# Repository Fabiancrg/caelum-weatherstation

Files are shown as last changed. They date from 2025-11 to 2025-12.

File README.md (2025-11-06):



| Supported Targets | ESP32-C6 | ESP32-H2 |
| --- |  --- | --- |

# Caelum - Zigbee Weather Station




## Project Description

This project implements a battery-powered environmental monitoring device using ESP32-C6/H2 with Zigbee connectivity. The device features a 3-endpoint design with remote sleep configuration, optimized for low-power operation with deep sleep support and extended wake time during network join.

This project is based on the examples provided in the ESP Zigbee SDK:

* [ESP Zigbee SDK Docs](https://docs.espressif.com/projects/esp-zigbee-sdk)
* [ESP Zigbee SDK Repo](https://github.com/espressif/esp-zigbee-sdk)

## Device Features

### 🌐 Zigbee Endpoints Overview

| Endpoint | Device Type | Clusters | Description |
|---|---|---|---|
| **1** | Environmental Sensor | Temperature, Humidity, Pressure, Battery, OTA | BME280 sensor via I2C |
| **2** | Rain Gauge | Analog Input | Tipping bucket rain sensor with rainfall totals |
| **3** | Sleep Configuration | Analog Input | Remote sleep duration control (60-7200 seconds) |
| **4** | LED Debug Control | On/Off | WS2812 RGB LED status indicator (remote control) |

### 💡 LED Debug Feature (Optional)

The device includes an optional WS2812 RGB LED on GPIO8 (ESP32-H2 SuperMini) that provides visual feedback:
- **Blue (Steady)**: Connected to Zigbee network
- **Orange (Blinking)**: Joining/searching for network  
- **White (Brief Flash)**: Rain pulse detected
- **Off**: Deep sleep or disabled via Zigbee

This feature can be controlled remotely via Zigbee2MQTT (endpoint 4) and disabled to conserve battery. See [LED_DEBUG_FEATURE.md](LED_DEBUG_FEATURE.md) for complete documentation.

### 📋 Detailed Endpoint Descriptions

#### **Endpoint 1: Environmental Monitoring & Power Management**
- **Hardware**: BME280 sensor via I2C
  - **ESP32-H2**: SDA: GPIO10, SCL: GPIO11
  - **ESP32-C6**: SDA: GPIO6, SCL: GPIO7
- **Measurements**: 
  - 🌡️ **Temperature**: -40°C to +85°C (±1°C accuracy)
  - 💧 **Humidity**: 0-100% RH (±3% accuracy) 
  - 🌪️ **Pressure**: 300-1100 hPa (±1 hPa accuracy)
  - 🔋 **Battery Monitoring**: Li-Ion voltage (2.7V-4.2V) and percentage
- **Battery Monitoring**:
  - **Hardware**: GPIO4 (ADC1_CH4) with voltage divider (2x 100kΩ resistors)
  - **Voltage**: Real-time battery voltage in 0.1V units
  - **Percentage**: Battery level 0-100% based on Li-Ion discharge curve
  - **Calibration**: ESP32-H2 ADC correction factor (1.604x) for accurate readings
  - **Power Configuration Cluster**: Standard Zigbee battery attributes
  - **Optimized Reading**: 
    - Time-based hourly intervals (3600 seconds) with NVS persistence
    - 3 ADC samples (reduced from 10) for ~70% ADC power savings
    - No delays between samples for ~90% overhead reduction
    - Total battery monitoring power: ~12µAh/day (98% reduction from ~480µAh/day)
    - Always reports on first boot/pairing, then hourly regardless of wake frequency
- **Features**: Automatic reporting during wake cycles, Zigbee-standard units
- **Use Case**: Weather monitoring, HVAC automation, air quality tracking, battery-powered applications

#### **Endpoint 2: Rain Gauge System**
- **Hardware**: Tipping bucket rain gauge with reed switch
  - **ESP32-H2**: GPIO12 (RTC-capable for sleep wake-up)
  - **ESP32-C6**: GPIO5 (RTC-capable for sleep wake-up)
- **Measurements**: Cumulative rainfall in millimeters (0.36mm per tip)
- **Features**: 
  - Advanced debouncing (200ms + 1000ms bounce settle)
  - Persistent storage (NVS) for total tracking
  - Smart reporting (1mm threshold OR hourly)
  - Network-aware operation (only active when connected)
  - **Both targets**: Wake from deep sleep on rain detection
  - **Time-based hourly reading**: Uses NVS persistence to ensure true 1-hour intervals regardless of wake frequency
- **Specifications**: 
  - Maximum rate: 200mm/hour supported
  - Accuracy: ±0.36mm per bucket tip
  - Storage: Non-volatile total persistence across reboots
  - Rain-proof interval tracking: Hourly battery reading even during frequent rain events
- **Use Case**: Weather station, irrigation control, flood monitoring

#### **Endpoint 3: Sleep Configuration**
- **Hardware**: Software-only (virtual endpoint)
- **Control**: Sleep duration in seconds (60-7200s range)
- **Features**:
  - Remote configuration via Zigbee2MQTT or Home Assistant
  - Persistent storage (NVS) - survives reboots
  - Real-time updates - changes apply on next wake cycle
  - Default: 900 seconds (15 minutes)
- **Use Case**: 
  - Battery optimization (longer intervals = longer battery life)
  - Seasonal adjustments (frequent updates in rainy season)
  - Dynamic power management based on weather conditions

#### **Endpoint 4: LED Debug Control**
- **Hardware**: WS2812 RGB LED (ESP32-H2 SuperMini)
  - **GPIO**: GPIO8
  - **Driver**: espressif/led_strip ~2.0.0
- **LED States**:
  - 🔵 **Blue (Steady)**: Connected to Zigbee network
  - 🟠 **Orange (Blinking)**: Searching/joining network
  - ⚪ **White (Flash)**: Rain pulse detected (100ms)
  - ⚫ **Off**: Deep sleep or disabled
- **Control**: On/Off cluster for remote enable/disable
- **Features**:
  - Remote control via Zigbee2MQTT switch
  - Default state: Enabled (ON)
  - Minimal battery impact (~20mA when active, off during sleep)
  - Visual feedback for debugging and network status
- **Use Case**: 
  - Development and testing (visual network status)
  - Field deployment debugging
  - Can be disabled remotely to conserve battery
- **Documentation**: See [LED_DEBUG_FEATURE.md](LED_DEBUG_FEATURE.md) for details

### 🔧 Hardware Configuration

#### **Required Components**
- ESP32-C6 or ESP32-H2 development board
- BME280 environmental sensor module
- Tipping bucket rain gauge with reed switch
- Li-Ion battery (with protection circuit, 5V output recommended)
- Voltage divider (2x 100kΩ resistors for battery monitoring)
- Zigbee coordinator (ESP32-H2 or commercial gateway)

#### **Pin Assignments**

**ESP32-H2 (Recommended)**
```
GPIO 4  - Battery voltage input (ADC1_CH4 with voltage divider)
GPIO 8  - WS2812 RGB LED (debug indicator, optional)
GPIO 9  - Built-in button (factory reset)
GPIO 10 - I2C SDA (BME280)
GPIO 11 - I2C SCL (BME280) 
GPIO 12 - Rain gauge input (RTC-capable)*
```

**ESP32-C6**
```
GPIO 4  - Battery voltage input (ADC1_CH4 with voltage divider)
GPIO 5  - Rain gauge input (RTC-capable)*
GPIO 6  - I2C SDA (BME280)
GPIO 7  - I2C SCL (BME280) 
GPIO 9  - Built-in button (factory reset)
```

*Both targets now use RTC-capable GPIO pins for rain detection during deep sleep

**Battery Voltage Divider Circuit**
```
Battery+ ──┬── 100kΩ ──┬── 100kΩ ── GND
           │           │
           │           └── GPIO4 (ADC input)
           │
           └── 5V output (to ESP32 power)
```
Note: Voltage divider monitors the cell voltage (2.7V-4.2V) while the battery pack provides 5V regulated output

### � Zigbee Integration
- **Protocol**: Zigbee 3.0  
- **Device Type**: End Device (sleepy end device for battery operation)
- **Supported Channels**: 11-26 (2.4 GHz)
- **Compatible**: Zigbee2MQTT, Home Assistant ZHA, Hubitat
- **OTA Support**: Over-the-air firmware updates enabled (see [OTA_GUIDE.md](OTA_GUIDE.md))

### ⚡ Power Management
- **Deep Sleep Mode**: Configurable intervals (60-7200 seconds, default 15 minutes)
  - **Configurable via Zigbee2MQTT**: Adjust sleep duration remotely from Home Assistant
  - **Connected**: Uses configured interval (default 15 minutes)
  - **Disconnected**: 30-second intervals for quick reconnection
  - **Max retries**: After 20 attempts (10 minutes), reduces to half configured duration
  - **Extended wake time**: Device stays awake for 60 seconds when not connected (instead of 10s) to allow Zigbee join process to complete
- **Wake-up Sources**:
  - Timer (configurable 60-7200 seconds)
  - **Rain detection during deep sleep** (both targets support RTC wake-up)
    - **ESP32-H2**: GPIO12 (RTC-capable)
    - **ESP32-C6**: GPIO5 (RTC-capable)
- **Network Retry Logic**: 
  - Prevents deep sleep when not connected to ensure reliable pairing
  - Extended 60-second wake period for join process completion
  - Connection success triggers 15-second reporting window before sleep
- **Battery Life**: Optimized for extended operation on battery power
  - **Total Power Consumption**: ~230µAh/day (optimized from ~700µAh/day)
  - **Battery monitoring**: ~12µAh/day (hourly readings with time-based intervals)
  - **Deep sleep**: 7-10µA baseline
  - **Active time**: ~100mA during 15-minute wake cycles
- **Battery Estimate**: 
  - **2500mAh battery**: ~10.9 years (optimized from ~3.5 years)
  - **Optimization breakdown**: 
    - 3 ADC samples instead of 10 (70% ADC power savings)
    - No delays between samples (90% overhead reduction)
    - Time-based hourly intervals (vs. every wake cycle)
    - Total battery monitoring: 98% power reduction

## 🚀 Quick Start

### Prerequisites

```bash
# Install ESP-IDF v5.5.1 or later
git clone -b v5.5.1 --recursive https://github.com/espressif/esp-idf.git
cd esp-idf
# For ESP32-H2 (recommended)
./install.sh esp32h2
# For ESP32-C6
./install.sh esp32c6
. ./export.sh
```

### Configure the Project
```bash
# For ESP32-H2 (recommended for better power management)
idf.py set-target esp32h2
# For ESP32-C6  
idf.py set-target esp32c6
idf.py menuconfig
```

### Build and Flash
```bash
# Erase previous data (recommended for first flash)
idf.py -p [PORT] erase-flash

# Build and flash the project
idf.py -p [PORT] flash monitor
```

### 🛠️ Configuration

### Device Operation

#### **Factory Reset**
- **Built-in Button (GPIO 9)**:
  - Long press (5s): Factory reset device

#### **Automatic Features**
- Environmental data reported during wake cycles
- Rain gauge totals stored persistently in NVS
- Smart rainfall reporting (1mm increments or hourly)
- Network connection status monitoring
- Deep sleep after data reporting (15-second window when connected, 60 seconds when not connected)
- Sleep duration remotely configurable via Zigbee2MQTT (60-7200 seconds)

### 📡 Data Reporting
- **Temperature/Humidity/Pressure**: Reported during wake cycles
- **Rainfall**: Immediate on tip detection (>1mm) or hourly
- **Sleep Duration**: Configurable 60-7200 seconds (default 15 minutes)
- **Sleep Cycle**: Configurable via Endpoint 3 for battery optimization

## 📊 Example Output

### Device Initialization
```
I (403) app_start: Starting scheduler on CPU0
I (408) WEATHER_STATION: Initialize Zigbee stack
I (558) WEATHER_STATION: Deferred driver initialization successful
I (568) WEATHER_STATION: BME280 sensor initialized successfully
I (578) WEATHER_STATION: Rain gauge initialized. Current total: 0.00 mm
I (578) WEATHER_STATION: Start network steering
```

### Network Connection
```
I (3558) WEATHER_STATION: Joined network successfully (Extended PAN ID: 74:4d:bd:ff:fe:63:f7:30, PAN ID: 0x13af, Channel:13, Short Address: 0x7c16)
I (3568) RAIN_GAUGE: Rain gauge enabled - device connected to Zigbee network
```

### Sensor Data Reporting
```
I (8000) WEATHER_STATION: 🌡️ Temperature: 22.35°C reported to Zigbee  
I (8010) WEATHER_STATION: 💧 Humidity: 45.20% reported to Zigbee
I (8020) WEATHER_STATION: 🌪️ Pressure: 1013.25 hPa reported to Zigbee
I (8030) BATTERY: 🔋 Li-Ion Battery: 4.17V (98%) - Zigbee values: 41 (0.1V), 196 (%*2)
I (8040) WEATHER_STATION: 📡 Temp: 22.4°C
I (8050) WEATHER_STATION: 📡 Humidity: 45.2%
I (8060) WEATHER_STATION: 📡 Pressure: 1013.3 hPa
```

### Rain Gauge Activity
```  
I (10000) RAIN_GAUGE: 🔍 Rain gauge interrupt received on GPIO18 (enabled: YES)
I (10010) RAIN_GAUGE: 🌧️ Rain pulse #1 detected! Total: 0.36 mm (+0.36 mm)
I (10020) RAIN_GAUGE: ✅ Rainfall total 0.36 mm reported to Zigbee
I (10030) WEATHER_STATION: 📡 Rain: 0.36 mm
```

### Deep Sleep Entry
```
I (18000) WEATHER_STATION: ⏳ Preparing for deep sleep...
I (18010) WEATHER_STATION: 💤 Entering deep sleep for 900 seconds (15 minutes)
```

## 🏠 Home Assistant Integration

When connected to Zigbee2MQTT or other Zigbee coordinators, the device appears as:

- **4x Sensor entities**: Temperature, Humidity, Pressure, Battery Percentage
- **1x Sensor entity**: Battery Voltage (mV)
- **1x Sensor entity**: Rainfall total with automatic updates
- **1x Number entity**: Sleep duration control (60-7200 seconds)
- **1x Switch entity**: LED debug control (enable/disable status indicator)

### Zigbee2MQTT Integration

A custom external converter is provided for full feature support with Zigbee2MQTT. See [ZIGBEE2MQTT_CONVERTER.md](ZIGBEE2MQTT_CONVERTER.md) for:
- Converter installation instructions
- Multi-endpoint support configuration
- Sleep duration control setup
- Home Assistant automation examples

### Device Information
- **Manufacturer**: ESPRESSIF
- **Model**: caelum
- **Firmware Version**: Managed via CMakeLists.txt (PROJECT_VER, BUILD_NUMBER)
  - Generated header approach using `version.h.in` template
  - Single source of truth for all version macros
  - Automatically propagated to Zigbee Basic cluster attributes
- **Supported**: Zigbee2MQTT with custom external converter (`caelum-weather-station.js`)

## 🔧 Configuration

### Version Management

Version information is centrally managed in `CMakeLists.txt`:

```cmake
set(PROJECT_VER "1.0")           # Major.Minor version
set(BUILD_NUMBER 0)              # Build/patch number
```

The build system automatically:
- Generates `build/generated/version.h` from `version.h.in` template
- Populates all version macros (FW_VERSION, FW_DATE_CODE, OTA_FILE_VERSION, etc.)
- Propagates to Zigbee Basic cluster (swBuildId, dateCode, applicationVersion)
- Updates OTA cluster attributes for firmware update tracking

### Application Configuration

Key parameters can be adjusted in `main/esp_zb_weather.h`:
- Default sleep duration: 900 seconds (15 minutes) - can be changed via Endpoint 3
- Sleep duration range: 60-7200 seconds (1 minute to 2 hours)
- Network retry interval: 30 seconds when disconnected
- Maximum connection retries: 20 attempts before reducing sleep interval
- Rain tip bucket volume: 0.36mm per tip
- Extended wake time: 60 seconds when not connected (for join process)
- **Battery monitoring interval**: 3600 seconds (1 hour) - time-based with NVS persistence
- **Battery ADC samples**: 3 samples averaged (optimized from 10)
- **Battery monitoring power**: ~12µAh/day (98% reduction from original ~480µAh/day)
- **LED Debug**: Optional WS2812 RGB LED on GPIO8 (ESP32-H2), controllable via Zigbee

## 📝 Project Structure

```
WeatherStation/
├── main/
│   ├── esp_zb_weather.c     # Main Zigbee stack, 4-endpoint logic, network retry, LED control
│   ├── esp_zb_weather.h     # Configuration, endpoint definitions, LED settings
│   ├── esp_zb_ota.c         # OTA update implementation
│   ├── esp_zb_ota.h         # OTA interface
│   ├── sleep_manager.c      # Deep sleep management with RTC GPIO support
│   ├── sleep_manager.h      # Sleep manager interface
│   ├── bme280_app.c         # BME280 sensor driver with board-specific I2C
│   ├── bme280_app.h         # BME280 interface
│   ├── weather_driver.c     # DEPRECATED: Legacy driver (unused)
│   └── weather_driver.h     # DEPRECATED: Legacy interface (unused)
├── Doc/
│   └── README_GIT.md        # Git workflow guide for team (Azure DevOps)
├── caelum-weather-station.js # Zigbee2MQTT external converter (4 endpoints)
├── version.h.in             # Version header template (for configure_file)
├── CMakeLists.txt           # Build configuration with version generation
├── partitions.csv           # Partition table with OTA support
├── sdkconfig.defaults       # Default SDK settings
├── OTA_GUIDE.md            # OTA update instructions
├── LED_DEBUG_FEATURE.md    # LED debug feature documentation
└── README.md               # This file
```

## 🔧 Troubleshooting

### Common Issues

#### **Rain Gauge Not Detecting**
- **ESP32-H2**: Verify GPIO12 connections and reed switch operation
- **ESP32-C6**: Verify GPIO5 connections and reed switch operation
- Check that device is connected to Zigbee network (rain gauge only active when connected)
- Ensure proper pull-down resistor on rain gauge input
- Both targets support rain detection during deep sleep

#### **BME280 Not Reading**  
- **ESP32-H2**: Check I2C connections (SDA: GPIO10, SCL: GPIO11)
- **ESP32-C6**: Check I2C connections (SDA: GPIO6, SCL: GPIO7)
- Verify BME280 I2C address (default: 0x76 or 0x77)
- Ensure proper power supply to sensor (3.3V)

#### **Battery Monitoring Issues**
- Verify voltage divider connections (2x 100kΩ resistors to GPIO4)
- Check battery cell voltage tap (should be 2.7V-4.2V at divider output)
- Ensure GPIO4 (ADC1_CH4) is properly configured
- Monitor serial output for ADC calibration messages
- **ESP32-H2 ADC quirk**: Uses empirical correction factor (1.604x) for DB_12 attenuation
- Battery percentage calculated from voltage (2.7V=0%, 4.2V=100%)
- **Optimized reading schedule**: 
  - First reading always happens on boot/pairing
  - Subsequent readings every hour (3600 seconds) based on elapsed time
  - Uses NVS to persist timestamp across deep sleep cycles
  - Robust to frequent wake-ups (e.g., during rain events)

#### **Zigbee Connection Issues**
- Perform factory reset with long press (5s) on built-in button
- Ensure Zigbee coordinator is in pairing mode
- Check channel compatibility between coordinator and device
- **Auto-retry**: Device automatically retries every 30 seconds when disconnected
- **Extended wake time**: Device now stays awake for 60 seconds (instead of 10s) during join attempts
- **Battery impact**: Extended connection attempts may drain battery faster
- **Join timing**: Allow full 60 seconds for device to complete Zigbee join process

#### **Device Not Waking from Sleep**
- Check battery voltage (minimum 3.0V recommended)
- Verify wake-up sources (timer, rain gauge)
- Review sleep manager logs for errors
- **Network dependency**: Device stays awake longer when not connected to network

#### **High Battery Drain**
- Check if device is stuck in connection retry mode (30-second intervals)
- Verify Zigbee network is stable and accessible
- Monitor connection retry count in device logs
- Consider factory reset if connection issues persist
- **Battery monitoring optimization**: Should consume only ~12µAh/day (hourly readings)
- **Total optimized power**: ~230µAh/day → 10.9 year battery life (2500mAh battery)
- **LED Debug**: If enabled, LED consumes ~20mA during wake cycles (can be disabled via Zigbee)

#### **LED Not Working**
- **ESP32-H2 SuperMini**: Verify GPIO8 connection to WS2812 RGB LED
- Check LED debug feature is enabled in `esp_zb_weather.h` (`DEBUG_LED_ENABLE=1`)
- Verify LED debug is enabled via Zigbee2MQTT switch (endpoint 4)
- Monitor serial output for LED initialization messages
- Ensure led_strip component (~2.0.0) is properly installed
- **LED States**: Blue=connected, Orange blink=joining, White flash=rain, Off=sleep/disabled
- See [LED_DEBUG_FEATURE.md](LED_DEBUG_FEATURE.md) for detailed troubleshooting

### 📋 Development Notes

- **ESP-IDF Version**: v5.5.1 recommended
- **Zigbee SDK**: Latest ESP Zigbee SDK required  
- **Memory Usage**: ~2MB flash, ~200KB RAM typical
- **Power Consumption**: 
  - Active: ~100mA
  - Deep sleep: 7-10µA
  - Battery monitoring: ~12µAh/day (optimized)
  - **Total**: ~230µAh/day (3.1× improvement from ~700µAh/day)
- **Battery Operation**: Optimized for CR123A or Li-ion battery packs
  - **2500mAh battery**: ~10.9 years (vs. 3.5 years before optimization)
- **Target Support**: Both ESP32-H2 and ESP32-C6 fully support RTC GPIO wake-up for rain detection
- **Version Management**: Centralized in CMakeLists.txt with generated header approach

## 🔄 OTA Updates

This project supports Over-The-Air (OTA) firmware updates via Zigbee network. See [OTA_GUIDE.md](OTA_GUIDE.md) for detailed instructions on:
- Creating OTA images
- Configuring Zigbee2MQTT for OTA
- Performing updates
- Troubleshooting OTA issues

## 📄 License

This project follows dual licensing:
- **Software**: GNU General Public License v3.0 (see [LICENSE](LICENSE))
- **Hardware**: Creative Commons Attribution-NonCommercial-ShareAlike 4.0 (see [LICENSE-hardware](LICENSE-hardware))

## 🔄 Based On

This project is derived from ESP32 Zigbee SDK examples and implements a 4-endpoint architecture optimized for battery-powered weather station applications with:
- Remote sleep duration configuration (Endpoint 3)
- LED debug status indicator with remote control (Endpoint 4)
- Deep sleep power management with network retry logic
- Extended wake time during Zigbee join process (60 seconds)
- RTC GPIO wake-up support for rain detection on both ESP32-H2 and ESP32-C6
- Optimized battery monitoring with 98% power reduction

## 🤝 Contributing

Contributions are welcome! Please feel free to submit issues or pull requests.

For technical queries, please open an issue on GitHub. Include:
- Complete serial monitor output
- Hardware configuration details  
- ESP-IDF and SDK versions
- Specific symptoms and reproduction steps

## 💖 Support

If you find this project useful, consider supporting the development:



---

**Project**: Caelum - ESP32 Zigbee Weather Station  
**Version**: Managed via CMakeLists.txt (PROJECT_VER, BUILD_NUMBER)  
**Compatible**: ESP32-C6, ESP32-H2, ESP-IDF v5.5.1+  
**License**: GPL v3 (Software) / CC BY-NC-SA 4.0 (Hardware)  
**Features**: 
- 4-endpoint design (sensors, rain, sleep config, LED debug)
- Remote sleep configuration and LED control via Zigbee
- OTA firmware updates
- RTC GPIO wake-up for rain detection
- Optimized battery monitoring (~98% power reduction)
- Time-based hourly intervals with NVS persistence
- WS2812 RGB LED status indicator (optional)
- 10.9 year battery life (2500mAh, 15-min intervals)

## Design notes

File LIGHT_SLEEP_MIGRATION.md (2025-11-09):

# Light Sleep Migration Guide

## Overview
This document describes the migration from deep sleep to light sleep mode for the ESP32-H2 Zigbee Weather Station.

## Key Changes

### 1. Sleep Mode
- **Before:** Deep sleep mode - full device reset, RAM lost, Zigbee stack restarted
- **After:** Light sleep mode - RAM retained, Zigbee stack stays active, instant wake-up

### 2. Power Consumption
- **Deep Sleep:** ~5 µA → ~1.7 years battery life (2500 mAh)
- **Light Sleep:** ~150-300 µA → ~1-2 years battery life (2500 mAh)

### 3. Wake-Up Behavior
- **Deep Sleep:** 
  - Device restarts from scratch
  - 2-5 seconds to rejoin Zigbee network
  - "Device announce" messages in Zigbee2MQTT logs
  
- **Light Sleep:**
  - Device continues from where it left off
  - Instant message delivery (~100ms)
  - No "device announce" messages
  - Zigbee network connection maintained

### 4. Code Changes

#### Files Modified:
1. `main/sleep_manager.h` - Updated function declarations and comments
2. `main/sleep_manager.c` - Replaced `enter_deep_sleep()` with `enter_light_sleep()`
3. `main/esp_zb_weather.c` - Updated sleep preparation and wake-up logic

#### Key Function Changes:
- `enter_deep_sleep()` → `enter_light_sleep()`
- `prepare_for_deep_sleep()` → `prepare_for_light_sleep()`
- `deep_sleep_scheduled` → `sleep_scheduled`

#### Important Behavioral Changes:
1. **Zigbee Stack:**
   - No longer calls `esp_zb_sleep_enable(true)` before sleep
   - Stack automatically enters low-power mode during light sleep
   - No stack restart or network rejoin needed

2. **Wake-Up Flow:**
   - After `enter_light_sleep()` returns, execution continues
   - Schedules sensor reporting immediately after wake
   - Schedules next sleep cycle
   - LED turns back on if network is connected

3. **GPIO Wake-Up:**
   - Light sleep supports any GPIO (not just RTC-capable pins)
   - Uses `gpio_wakeup_enable()` instead of RTC GPIO functions

## Benefits of Light Sleep

### ✅ Advantages:
1. **Instant Responsiveness** - Messages sent immediately on wake (100ms vs 2-5s)
2. **No Network Rejoin** - Stays connected to Zigbee network
3. **Faster Rain Detection** - Immediate reporting on rain pulses
4. **Cleaner Logs** - No "device announce" spam in Zigbee2MQTT
5. **More Reliable** - No risk of network rejoin failures

### ⚠️ Trade-offs:
1. **Higher Power** - ~30-60x higher sleep current (150-300µA vs 5µA)
2. **Shorter Battery Life** - ~1-2 years vs ~1.7 years (still excellent for most use cases)
3. **Requires Periodic Wake** - Cannot sleep indefinitely

## Testing Recommendations

1. **Monitor Power Consumption:**
   - Measure actual sleep current with multimeter
   - Should see 150-300µA average during sleep
   - Compare to previous 5µA deep sleep baseline

2. **Test Wake-Up Speed:**
   - Trigger rain pulse manually
   - Check time until message appears in Zigbee2MQTT/Home Assistant
   - Should be < 500ms (vs 2-5s before)

3. **Battery Life Testing:**
   - Monitor battery voltage over several days
   - Estimate discharge rate
   - Verify 1-2 year projection

4. **Network Stability:**
   - Check for any "device offline" messages
   - Verify no "device announce" messages after wake
   - Confirm instant reporting after each wake cycle

## Reverting to Deep Sleep

If you need to revert to deep sleep:
1. Checkout the previous commit before this migration
2. Or manually replace:
   - `enter_light_sleep()` → `enter_deep_sleep()`
   - `prepare_for_light_sleep()` → `prepare_for_deep_sleep()`
   - `sleep_scheduled` → `deep_sleep_scheduled`
   - Add back `esp_zb_sleep_enable(true)` before sleep

## Next Steps

1. Build and flash the updated firmware:
   ```powershell
   idf.py build
   idf.py -p COM<X> flash monitor
   ```

2. Observe the logs for:
   - Successful light sleep entry
   - Wake-up messages with wake reason (TIMER or GPIO)
   - Immediate sensor reporting after wake
   - Next sleep cycle scheduling

3. Test in Zigbee2MQTT/Home Assistant:
   - Verify instant message delivery
   - Check battery reporting
   - Monitor for any connection issues

## Notes

- Light sleep is ideal for applications requiring fast response time
- Battery life is still excellent for most deployments (1-2 years)
- Consider deep sleep only if multi-year battery life is critical
- The Zigbee stack handles power management automatically in light sleep

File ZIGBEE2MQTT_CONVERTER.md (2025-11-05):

# Caelum Weather Station - Zigbee2MQTT External Converter

This external converter enables full integration of the Caelum Weather Station with Zigbee2MQTT and Home Assistant.

## Features

The converter provides the following entities:

### Environmental Sensors (Endpoint 1)
- **Temperature** - BME280 sensor readings (-40°C to +85°C)
- **Humidity** - Relative humidity (0-100% RH)  
- **Pressure** - Atmospheric pressure (300-1100 hPa)

### Rain Gauge (Endpoint 2)
- **Total Rainfall** - Cumulative rainfall in millimeters
- **Real-time updates** - Reports immediately on rain detection
- **Persistent storage** - Values persist through device reboots

### Sleep Configuration (Endpoint 3)  
- **Sleep Duration** - Configurable wake-up interval (60-7200 seconds)
- **Remote control** - Adjust sleep timing from Home Assistant
- **Battery optimization** - Longer intervals = better battery life

## Installation

1. **Copy the converter file** to your Zigbee2MQTT data directory:
   ```bash
   cp caelum-weather-station.js /opt/zigbee2mqtt/data/
   ```
   
   > **Note**: For Zigbee2MQTT v1.33.0+, converters placed in the `data` directory are automatically loaded.
   > For older versions, you may need to create an `external_converters` subdirectory and update `configuration.yaml`:
   > ```yaml
   > external_converters:
   >   - caelum-weather-station.js
   > ```

2. **Restart Zigbee2MQTT** to load the converter

3. **Pair the device** using the built-in button (long press for factory reset)

## Home Assistant Integration

Once paired, the device will automatically appear in Home Assistant with the following entities:

### Sensors
- `sensor.caelum_weather_station_temperature`
- `sensor.caelum_weather_station_humidity` 
- `sensor.caelum_weather_station_pressure`
- `sensor.caelum_weather_station_rainfall`
- `sensor.caelum_weather_station_battery`

### Configuration
- `number.caelum_weather_station_sleep_duration` (60-7200 seconds)

## Usage Examples

### Basic Weather Monitoring
```yaml
# automation.yaml
- alias: "Rain Alert"
  trigger:
    platform: numeric_state
    entity_id: sensor.caelum_weather_station_rainfall
    above: 5.0  # 5mm of rain
  action:
    service: notify.mobile_app
    data:
      message: "Rain detected: {{ states('sensor.caelum_weather_station_rainfall') }}mm"
```

### Dynamic Sleep Configuration
```yaml
# Shorter intervals during rain season
- alias: "Rain Season - Frequent Updates"
  trigger:
    platform: time
    at: "06:00:00"
  condition:
    condition: template
    value_template: "{{ now().month in [6,7,8,9] }}"  # Rain season
  action:
    service: number.set_value
    target:
      entity_id: number.caelum_weather_station_sleep_duration
    data:
      value: 300  # 5 minutes

# Longer intervals during dry season  
- alias: "Dry Season - Battery Conservation"
  trigger:
    platform: time
    at: "06:00:00"
  condition:
    condition: template
    value_template: "{{ now().month in [12,1,2,3] }}"  # Dry season
  action:
    service: number.set_value
    target:
      entity_id: number.caelum_weather_station_sleep_duration
    data:
      value: 1800  # 30 minutes
```

### Battery Monitoring
```yaml
- alias: "Low Battery Alert"
  trigger:
    platform: numeric_state
    entity_id: sensor.caelum_weather_station_battery
    below: 20
  action:
    service: notify.persistent_notification
    data:
      title: "Weather Station Battery Low"
      message: "Battery: {{ states('sensor.caelum_weather_station_battery') }}%"
```

## Reporting Intervals

- **Temperature**: 30s-15min (or 0.5°C change)
- **Humidity**: 30s-15min (or 2% change) 
- **Pressure**: 30s-15min (or 1 hPa change)
- **Rainfall**: Immediate (or hourly maximum)
- **Sleep Duration**: When changed (or hourly maximum)

## Troubleshooting

### Device Not Pairing
1. Ensure device is in factory reset mode (long press button)
2. Check Zigbee2MQTT logs for pairing attempts
3. Verify converter is loaded in external_converters

### Missing Entities
1. Check that all 3 endpoints are discovered (1, 2, 3)
2. Verify converter configuration in Zigbee2MQTT
3. Restart Home Assistant to refresh entity registry

### Configuration Not Working
1. Ensure sleep_duration is within valid range (60-7200)
2. Check device logs for configuration acceptance
3. Verify endpoint 3 is properly bound

### Battery Issues
1. Monitor voltage levels in device logs
2. Adjust sleep duration for better battery life
3. Check for stuck in wake state (short sleep intervals)

## Technical Details

- **Zigbee Device Type**: End Device (sleepy)
- **Clusters Used**: Basic, Temperature, Humidity, Pressure, Analog Input
- **Endpoints**: 3 (Environmental, Rain, Config)
- **OTA Support**: Yes (automatic updates)
- **Power**: Battery optimized with configurable sleep

For more information, see the main project documentation.

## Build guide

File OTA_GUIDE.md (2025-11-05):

# OTA (Over-The-Air) Firmware Update Guide

## Overview

The Weather Station now supports OTA (Over-The-Air) firmware updates via Zigbee network. This allows you to update the device firmware remotely without physical access to the device.

## Features

- **Automatic firmware validation**: New firmware runs in validation mode on first boot
- **Rollback protection**: If new firmware crashes, device automatically rolls back to previous version
- **Progress tracking**: OTA progress logged during update
- **Zero-copy header skipping**: Zigbee OTA header is automatically detected and skipped

## Firmware Version

The current firmware version is defined in the project's `CMakeLists.txt`:

```cmake
project(WeatherStation VERSION 1.0.0)
```

The version format is `MAJOR.MINOR.PATCH` (semantic versioning).

## OTA Configuration

### Device Configuration
- **Manufacturer Code**: `0xFABC` (DIY manufacturer code)
- **Image Type**: `0x1000`
- **OTA Endpoint**: Endpoint 1 (first light endpoint)

### Partition Table

Ensure your `partitions.csv` includes OTA partitions:

```csv
# Name,   Type, SubType, Offset,  Size, Flags
nvs,      data, nvs,     0x9000,  0x6000,
phy_init, data, phy,     0xf000,  0x1000,
factory,  app,  factory, 0x10000, 0x100000,
ota_0,    app,  ota_0,   ,        0x100000,
ota_1,    app,  ota_1,   ,        0x100000,
```

## Creating OTA Images

### Step 1: Build the Firmware

```bash
idf.py build
```

This creates the binary at: `build/WeatherStation.bin`

### Step 2: Convert to Zigbee OTA Format

Use the `esp_ota_image_create` tool from ESP-Zigbee-SDK:

```bash
python esp_ota_image_create.py \
    --manufacturer-code 0xFABC \
    --image-type 0x1000 \
    --file-version 0x01000100 \
    --min-hw-version 0 \
    --max-hw-version 0 \
    build/WeatherStation.bin \
    WeatherStation_v1.0.1.ota
```

**Version Format**: `0xMMmmpppp`
- `MM` = Major version (1 byte)
- `mm` = Minor version (1 byte)  
- `pppp` = Patch version (2 bytes)

Example: Version 1.0.1 = `0x01000100`

### Step 3: Upload to Zigbee2MQTT

1. Place the `.ota` file in your Zigbee2MQTT `ota` directory:
   ```bash
   cp WeatherStation_v1.0.1.ota /path/to/zigbee2mqtt/data/ota/
   ```

2. Configure Zigbee2MQTT to use custom OTA directory in `configuration.yaml`:
   ```yaml
   ota:
     zigbee_ota_override_index_location: data/ota/index.json
   ```

3. Create `data/ota/index.json`:
   ```json
   [
     {
       "fileVersion": 16777472,
       "fileSize": 1048576,
       "manufacturerCode": 64188,
       "imageType": 4096,
       "url": "WeatherStation_v1.0.1.ota"
     }
   ]
   ```

   **Note**: 
   - `fileVersion`: Decimal of 0x01000100 (version 1.0.1) = 16777472
   - `manufacturerCode`: Decimal of 0xFABC = 64188
   - `imageType`: Decimal of 0x1000 = 4096
   - `fileSize`: Size of the .ota file in bytes

## Performing OTA Update

### Via Zigbee2MQTT Web UI

1. Go to the device page in Zigbee2MQTT
2. Click on "OTA" tab
3. Click "Check for updates"
4. If update is available, click "Update"

### Via MQTT

```bash
# Check for update
mosquitto_pub -t 'zigbee2mqtt/WeatherStation/ota_update/check' -m ''

# Start update
mosquitto_pub -t 'zigbee2mqtt/WeatherStation/ota_update/update' -m ''
```

## OTA Update Process

1. **Query**: Device queries coordinator for available OTA images
2. **Download**: Device downloads firmware in chunks
3. **Verify**: Device verifies the downloaded image
4. **Apply**: Device sets new partition as boot partition
5. **Reboot**: Device reboots into new firmware
6. **Validate**: New firmware runs in validation mode
7. **Confirm**: If stable, firmware marks itself as valid

## Monitoring OTA Progress

View device logs during OTA update:

```
I (12345) ESP_ZB_OTA: === OTA UPGRADE STARTED ===
I (12346) ESP_ZB_OTA: OTA write session started
I (12400) ESP_ZB_OTA: First chunk received: 64 bytes
I (12401) ESP_ZB_OTA: Found ESP32 magic byte (0xE9) at offset 56
I (62500) ESP_ZB_OTA: OTA progress: 50000 bytes written
I (112600) ESP_ZB_OTA: OTA progress: 100000 bytes written
I (200000) ESP_ZB_OTA: === OTA UPGRADE APPLY ===
I (200100) ESP_ZB_OTA: Verifying OTA image...
I (200200) ESP_ZB_OTA: New firmware version: 1.0.1
I (200300) ESP_ZB_OTA: ✓ OTA upgrade successful!
I (200400) ESP_ZB_OTA: Rebooting in 3 seconds...
```

After reboot:

```
I (5000) ESP_ZB_OTA: *** OTA UPDATE VALIDATION MODE ***
I (5001) ESP_ZB_OTA: New firmware is running but not yet validated
I (5002) ESP_ZB_OTA: ✓ OTA update validated successfully!
I (5003) ESP_ZB_OTA: New firmware is now permanent
```

## Troubleshooting

### Update Fails to Start

- **Check manufacturer code and image type match** in both device and OTA file
- **Verify partition table** has ota_0 and ota_1 partitions
- **Ensure OTA file is accessible** in Zigbee2MQTT ota directory

### Device Reboots to Old Firmware

- **Validation failed**: New firmware didn't call `esp_ota_mark_app_valid_cancel_rollback()`
- **Check logs** for crash or error before validation
- This is **normal behavior** if new firmware is unstable

### OTA Never Completes

- **Check Zigbee network stability**
- **Reduce distance** between device and coordinator
- **Avoid interference** from WiFi or other devices
- **Battery devices**: Ensure device stays awake during OTA

## Best Practices

1. **Test OTA images locally first** before deploying
2. **Increment version numbers** correctly for each release
3. **Keep previous working firmware** available for rollback
4. **Document changes** in each firmware version
5. **Monitor first boot** after OTA to ensure validation succeeds
6. **For battery devices**: Plan OTA updates when device is awake or trigger wake-up first

## Version History

- **v1.0.0**: Initial release with OTA support
- **v1.0.1**: (Example) Bug fixes and improvements

## References

- [ESP-IDF OTA Documentation](https://docs.espressif.com/projects/esp-idf/en/latest/esp32/api-reference/system/ota.html)
- [ESP-Zigbee OTA Documentation](https://docs.espressif.com/projects/esp-zigbee-sdk/en/latest/)
- [Zigbee2MQTT OTA Updates](https://www.zigbee2mqtt.io/guide/usage/ota_updates.html)

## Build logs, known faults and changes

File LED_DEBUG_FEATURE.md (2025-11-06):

# LED Debug Feature Documentation

## Overview

The Caelum Weather Station includes an LED debug feature that provides visual feedback about the device's operational state. This feature is controllable via Zigbee using endpoint 4.

## Hardware

- **LED Type**: WS2812 RGB LED (on ESP32-H2 SuperMini)
- **GPIO**: GPIO8
- **Driver**: espressif/led_strip ~2.0.0

## LED States

The LED displays different colors and patterns to indicate device status:

| State | Color | Pattern | Meaning |
|---|---|---|---|
| **Disconnected** | Orange | Blinking (500ms) | Device is joining/searching for Zigbee network |
| **Connected** | Blue | Steady | Device is connected to Zigbee network |
| **Rain Detection** | White | Brief flash (100ms) | Rain gauge pulse detected |
| **Sleeping** | Off | - | Device is in deep sleep mode |
| **Disabled** | Off | - | LED debug feature disabled via Zigbee |

## Zigbee Control

### Endpoint 4: LED Debug Control

The LED debug feature can be enabled/disabled remotely via Zigbee using endpoint 4:

- **Cluster**: genOnOff (0x0006)
- **Attribute**: onOff (0x0000)
- **Device Type**: On/Off Output (0x0002)
- **Default State**: Enabled (ON)

### Usage in Zigbee2MQTT

After pairing the device with Zigbee2MQTT, a switch entity will appear for "LED Debug":

```javascript
// In Z2M frontend:
// Switch: "LED Debug" - Toggle to enable/disable LED indicator

// Via MQTT:
mosquitto_pub -t 'zigbee2mqtt/caelum-weather-station/set' -m '{"state_4":"ON"}'   // Enable LED
mosquitto_pub -t 'zigbee2mqtt/caelum-weather-station/set' -m '{"state_4":"OFF"}'  // Disable LED
```

## Implementation Details

### Code Structure

**Files Modified:**
- `main/esp_zb_weather.h` - Added endpoint 4 definition and LED configuration
- `main/esp_zb_weather.c` - Implemented LED control functions and Zigbee endpoint
- `caelum-weather-station.js` - Added endpoint 4 to Z2M converter

**Key Components:**

1. **Control Variable** (`esp_zb_weather.c`):
   ```c
   static bool led_debug_enabled = true;  // Default: enabled
   ```

2. **LED Functions**:
   - `debug_led_init()` - Initialize WS2812 LED on GPIO8
   - `debug_led_set(bool state)` - Set LED on/off (respects led_debug_enabled)
   - `debug_led_start_blink()` - Start orange blinking for network joining
   - `debug_led_stop_blink()` - Stop blinking
   - `debug_led_rain_flash()` - White flash on rain detection

3. **Zigbee Attribute Handler**:
   ```c
   // Handles genOnOff writes on endpoint 4
   // Updates led_debug_enabled and immediately applies state
   ```

4. **Endpoint Configuration**:
   ```c
   esp_zb_endpoint_config_t endpoint_led_config = {
       .endpoint = HA_ESP_LED_DEBUG_ENDPOINT,  // 4
       .app_profile_id = ESP_ZB_AF_HA_PROFILE_ID,
       .app_device_id = ESP_ZB_HA_ON_OFF_OUTPUT_DEVICE_ID,
   };
   ```

### Behavior

**When Enabled (ON)**:
- LED shows network status (orange blink → blue solid)
- White flash on rain gauge pulses
- Turns off during deep sleep

**When Disabled (OFF)**:
- LED immediately turns off
- All LED functions skip execution
- Rain pulse detection continues (no visual feedback)
- Network operation unaffected

### Power Considerations

The LED debug feature has minimal impact on battery life:
- Only active during wake periods (~10-60 seconds)
- Off during deep sleep (majority of time)
- RGB LED draws ~20mA when on
- Can be disabled remotely to conserve battery in production deployments

## Configuration Options

Compile-time options in `esp_zb_weather.h`:

```c
#define DEBUG_LED_ENABLE 1          // Enable LED debug feature
#define DEBUG_LED_TYPE_RGB 1        // Use WS2812 RGB LED (0 = simple GPIO)
#define DEBUG_LED_GPIO GPIO_NUM_8   // GPIO pin for LED
```

For simple GPIO LED instead of WS2812:
```c
#define DEBUG_LED_TYPE_RGB 0        // Use simple GPIO LED
```

## Troubleshooting

**LED stays off**:
- Check if feature is enabled via Zigbee (endpoint 4 state)
- Verify DEBUG_LED_ENABLE=1 in esp_zb_weather.h
- Check GPIO8 connection to WS2812 LED
- Monitor logs for initialization errors

**LED doesn't flash on rain**:
- Verify rain gauge GPIO (default GPIO4) is connected
- Check Z2M for rainfall updates
- LED must be enabled and device must be awake

**Wrong colors**:
- Verify WS2812 LED type (not WS2811 or similar)
- Check led_strip component version (~2.0.0)
- Verify RMT channel configuration

## Future Enhancements

Potential improvements:
- NVS persistence for led_debug_enabled state
- Configurable LED brightness via Zigbee
- Additional color patterns for different events
- Low battery warning (red blink)

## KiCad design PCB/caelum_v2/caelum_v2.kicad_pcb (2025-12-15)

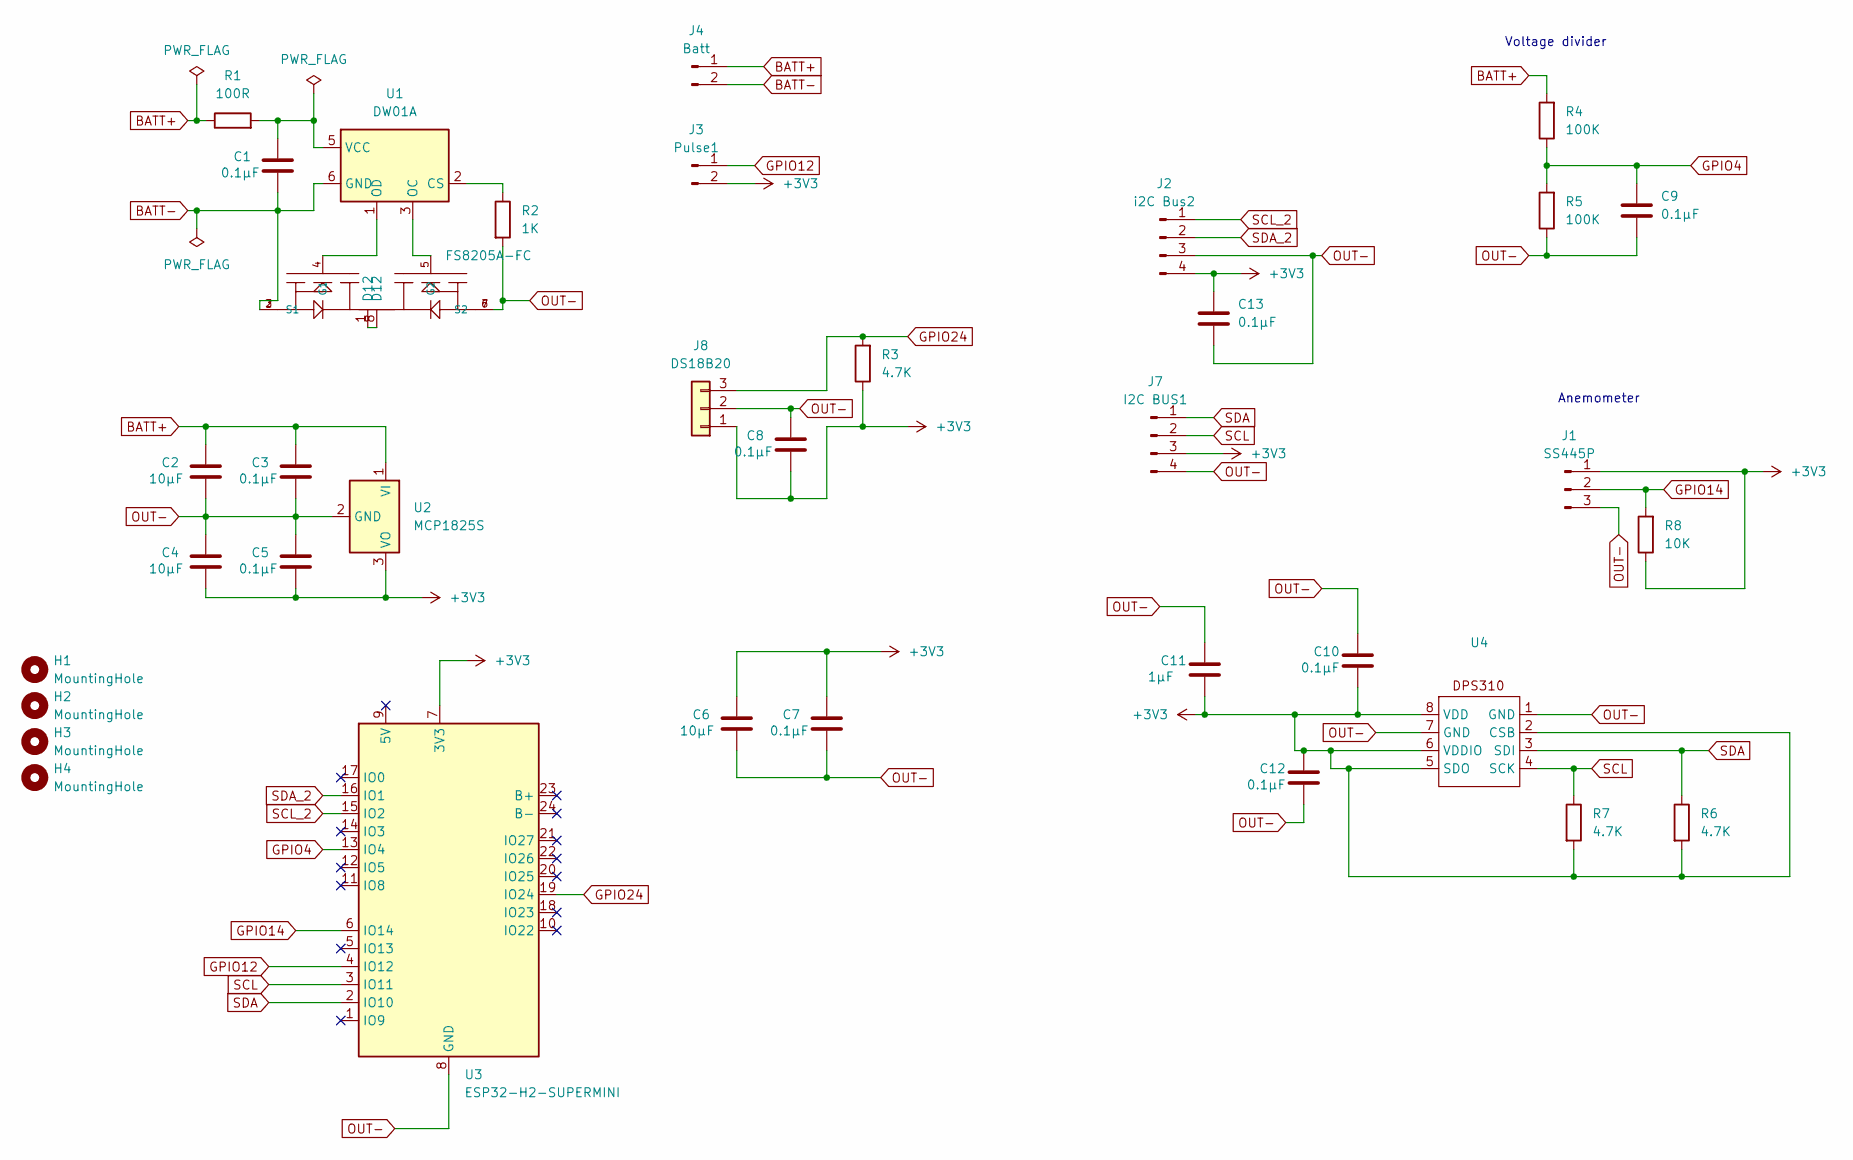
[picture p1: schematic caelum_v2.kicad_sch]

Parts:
C1, C3, C5, C7, C8, C9, C10, C12, C13: 0.1µF; C_0805_2012Metric
C2, C4, C6: 10µF; C_0805_2012Metric
C11: 1µF; C_0805_2012Metric
H1, H2, H3, H4: MountingHole; MountingHole_2.2mm_M2
J1: SS445P; Hirose_DF13C_CL535-0403-5-51_1x03-1MP_P1.25mm_Vertical
J2: i2C Bus2; JST_PH_B4B-PH-SM4-TB_1x04-1MP_P2.00mm_Vertical
J3: Pulse1; Hirose_DF13C_CL535-0402-2-51_1x02-1MP_P1.25mm_Vertical
J4: Batt; PinHeader_1x02_P2.54mm_Vertical
J7: I2C BUS1; JST_PH_S4B-PH-SM4-TB_1x04-1MP_P2.00mm_Horizontal
J8: DS18B20; Hirose_DF13C_CL535-0403-5-51_1x03-1MP_P1.25mm_Vertical
Q1: FS8205A-FC; SOP65P640X120-8N-FC; PARTREV 1.7
R1: 100R; R_0805_2012Metric
R2: 1K; R_0805_2012Metric
R3, R6, R7: 4.7K; R_0805_2012Metric
R4, R5: 100K; R_0805_2012Metric
R8: 10K; R_0805_2012Metric
U1: DW01A; SOT-23-6
U2: MCP1825S; SOT-223-3_TabPin2
U3: ESP32-H2-SUPERMINI; ESP32H2-Supermini
U4: Bosch_LGA-8_2x2.5mm_P0.65mm_ClockwisePinNumbering

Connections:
+3V3: C4.2, C5.2, C6.1, C7.1, C8.2, C10.2, C11.2, C12.1, C13.1, J1.1, J2.4, J3.2, J7.3, J8.1, R3.1, R6.2, R7.2, R8.1, U2.3 (VO), U3.7 (3V3), U4.2 (CSB), U4.5 (SDO), U4.6 (VDDIO), U4.8 (VDD)
BATT+: C2.1, C3.1, J4.1, R1.1, R4.2, U2.1 (VI)
BATT-: C1.2, J4.2, Q1.2 (S1), Q1.3 (S1), U1.6 (GND)
GPIO4: C9.1, R4.1, R5.2, U3.13 (IO4)
GPIO12: J3.1, U3.4 (IO12)
GPIO14: J1.2, R8.2, U3.6 (IO14)
GPIO24: J8.3, R3.2, U3.19 (IO24)
unnamed: Q1.1 (D12), Q1.8 (D12)
unnamed: Q1.4 (G1), U1.1 (OD)
unnamed: Q1.5 (G2), U1.3 (OC)
unnamed: R2.1, U1.2 (CS)
unnamed: C1.1, R1.2, U1.5 (VCC)
OUT-: C2.2, C3.2, C4.1, C5.1, C6.2, C7.2, C8.1, C9.2, C10.1, C11.1, C12.2, C13.2, J1.3, J2.3, J7.4, J8.2, Q1.6 (S2), Q1.7 (S2), R2.2, R5.1, U2.2 (GND), U3.8 (GND), U4.1 (GND), U4.7 (GND)
SCL: J7.2, R7.1, U3.3 (IO11), U4.4 (SCK)
SCL_2: J2.1, U3.15 (IO2)
SDA: J7.1, R6.1, U3.2 (IO10), U4.3 (SDI)
SDA_2: J2.2, U3.16 (IO1)

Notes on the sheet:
Anemometer
Voltage divider

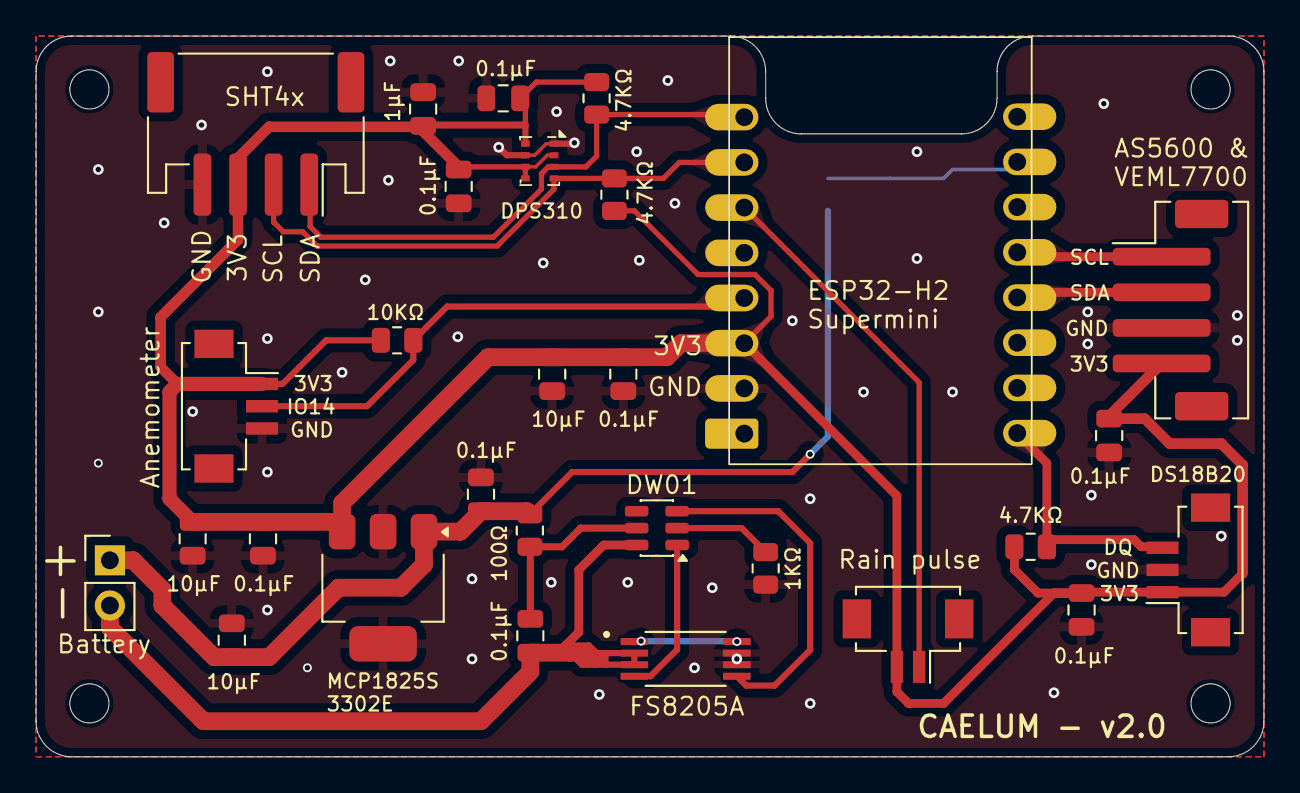
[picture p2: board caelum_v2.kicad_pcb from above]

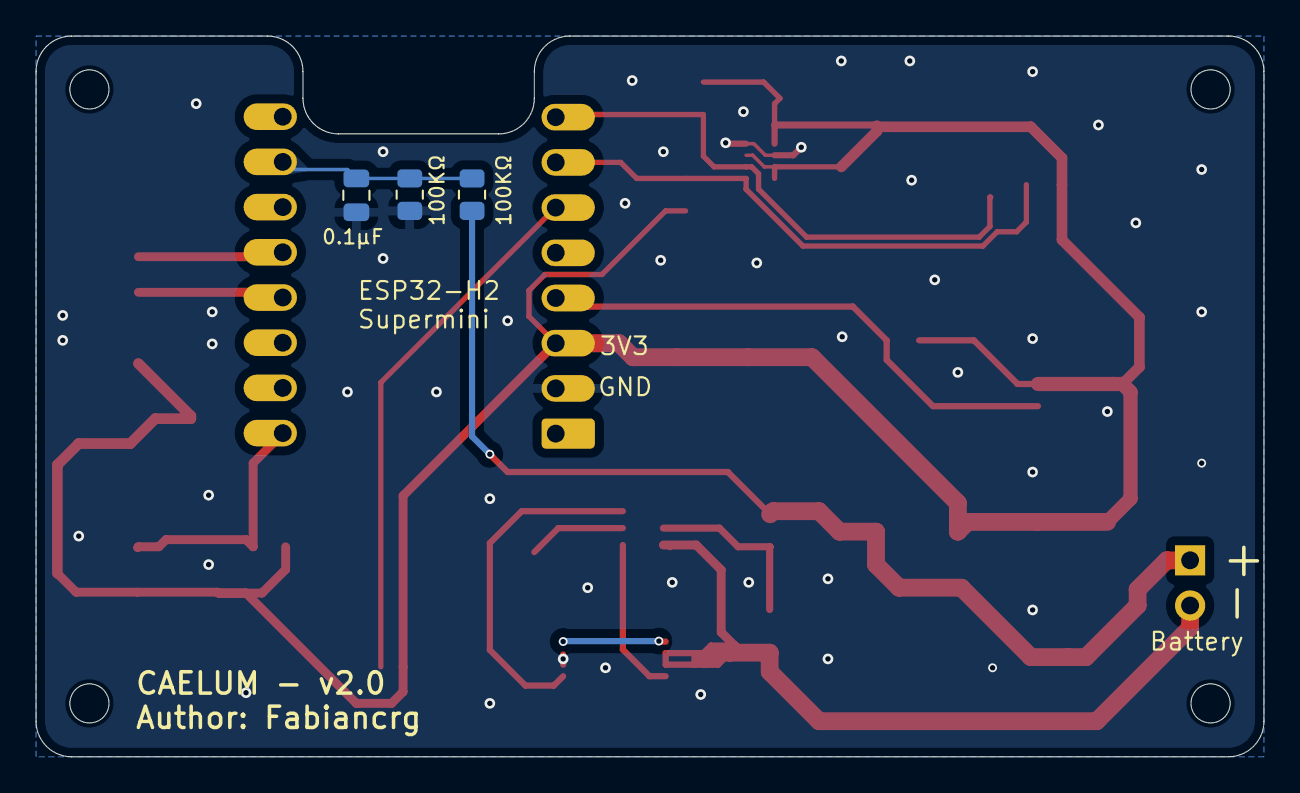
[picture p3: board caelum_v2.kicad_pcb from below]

Board: 2 copper layers, 69.0 x 40.5 mm, 36 parts (3 on the bottom side), 17 nets.

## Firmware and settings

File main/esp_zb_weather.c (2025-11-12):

/*
 * SPDX-FileCopyrightText: 2021-2024 Espressif Systems (Shanghai) CO LTD
 *
 * SPDX-License-Identifier:  LicenseRef-Included
 *
 * ESP32-H2 Zigbee Weather Station with Light Sleep
 *
 * Battery-powered weather station with 5-minute periodic sensor readings.
 * Rain gauge triggers immediate attribute updates on each pulse.
 * Uses light sleep to maintain Zigbee network connection.
 * All reporting controlled by Zigbee coordinator configuration.
 */
#include "freertos/FreeRTOS.h"
#include "freertos/task.h"
#include "freertos/queue.h"
#include "esp_check.h"
#include "esp_log.h"
#include "nvs_flash.h"
#include "ha/esp_zigbee_ha_standard.h"
#include "esp_zb_weather.h"
#include "esp_zb_ota.h"
#include "sleep_manager.h"
#include "driver/gpio.h"
#include "bme280_app.h"
#include "i2c_bus.h"
#include "nvs.h"
#include "weather_driver.h"
#include "esp_adc/adc_oneshot.h"
#include "esp_adc/adc_cali.h"
#include "esp_adc/adc_cali_scheme.h"
#include "esp_ota_ops.h"
#include "esp_app_format.h"
#include "esp_timer.h"
#include "esp_pm.h"
#include "esp_sleep.h"
#include "esp_rom_uart.h"
/* Generated header with FW_VERSION / FW_DATE_CODE - created at configure time */
#include "version.h"

/* OTA upgrade running versions */
#ifndef OTA_UPGRADE_RUNNING_FILE_VERSION
#define OTA_UPGRADE_RUNNING_FILE_VERSION                      0x00000000U
#endif
#ifndef OTA_UPGRADE_RUNNING_STACK_VERSION
#define OTA_UPGRADE_RUNNING_STACK_VERSION                     0x0002U
#endif

#if !defined ZB_ED_ROLE
#error Define ZB_ED_ROLE in idf.py menuconfig to compile Weather Station (End Device) source code.
#endif

/* Zigbee Sleepy End Device (SED) configuration */
#define ZIGBEE_KEEP_ALIVE_MS        7500    // Keep-alive poll interval (7.5 seconds)
#define ZIGBEE_SLEEP_THRESHOLD_MS   6000    // Idle time before sleep signal (6 seconds)
#define ZIGBEE_ED_TIMEOUT           ESP_ZB_ED_AGING_TIMEOUT_64MIN  // Parent timeout

/* Power optimization notes:
 * - Sleep threshold MUST be < keep_alive to allow CAN_SLEEP signal before next poll
 * - Lower threshold = faster sleep entry = better battery life
 * - Higher threshold = more time for multiple reports = fewer wake cycles
 * - Current setting (6s): Optimal for 15-min reporting with occasional rain events
 * - Measured performance: 0.68mA sleep, 12mA transmit, ~0.83mA average
 * - Battery life: ~125 days (4 months) on 2500mAh Li-Ion
 */

static const char *TAG = "WEATHER_STATION";
//static const char *RAIN_TAG = "RAIN_GAUGE";

/* Network connection status - declared early for LED functions */
static bool zigbee_network_connected = false;

/* LED is used only during boot/join process:
 * - Blink yellow/orange during network joining
 * - Steady blue when successfully connected
 * - Blink red after max connection retries failed
 * After successful join, LED strip is deinitialized to save power */

#include "led_strip.h"

/* Debug LED variables for RGB LED */
static led_strip_handle_t led_strip = NULL;
static bool led_blink_task_running = false;
static TaskHandle_t led_blink_task_handle = NULL;

/* LED control functions for WS2812 RGB LED */
static void debug_led_init(void)
{
    /* LED strip configuration for WS2812 (older API for led_strip ~2.0.0) */
    led_strip_config_t strip_config = {
        .strip_gpio_num = DEBUG_LED_GPIO,
        .max_leds = 1,                         // Only 1 LED
    };
    
    /* LED strip RMT configuration (older API) */
    led_strip_rmt_config_t rmt_config = {
        .resolution_hz = 10 * 1000 * 1000,     // 10MHz
    };
    
    ESP_ERROR_CHECK(led_strip_new_rmt_device(&strip_config, &rmt_config, &led_strip));
    
    /* Turn off LED initially */
    led_strip_clear(led_strip);
    ESP_LOGI(TAG, "Debug RGB LED initialized on GPIO%d (WS2812)", DEBUG_LED_GPIO);
}

static void debug_led_deinit(void)
{
    /* Deinitialize LED strip to power down RMT peripheral
     * Called after successful network join to save power */
    if (led_strip) {
        led_strip_clear(led_strip);  // Clear pixels first
        led_strip_del(led_strip);    // Delete LED strip handle (powers down RMT)
        led_strip = NULL;
        ESP_LOGI(TAG, "🔌 RGB LED RMT peripheral powered down (boot sequence complete)");
    }
}

static void debug_led_set_blue(void)
{
    /* Set steady blue for successful connection */
    if (led_strip) {
        led_strip_set_pixel(led_strip, 0, 0, 0, 16);  // R=0, G=0, B=16 (dim blue)
        led_strip_refresh(led_strip);
    }
}

static void debug_led_blink_task(void *arg)
{
    while (led_blink_task_running) {
        if (!led_strip) break;  // Stop if LED was deinitialized
        
        /* Yellow/orange blink for network joining */
        led_strip_set_pixel(led_strip, 0, 16, 8, 0);  // R=16, G=8, B=0 (dim yellow/orange)
        led_strip_refresh(led_strip);
        vTaskDelay(pdMS_TO_TICKS(500));  // ON for 500ms
        
        led_strip_set_pixel(led_strip, 0, 0, 0, 0);   // OFF
        led_strip_refresh(led_strip);
        vTaskDelay(pdMS_TO_TICKS(500));  // OFF for 500ms
    }
    vTaskDelete(NULL);
}

static void debug_led_start_blink(void)
{
    if (!led_strip) return;  // LED already deinitialized
    
    if (!led_blink_task_running) {
        led_blink_task_running = true;
        xTaskCreate(debug_led_blink_task, "led_blink", 2048, NULL, 5, &led_blink_task_handle);
        ESP_LOGI(TAG, "RGB LED blink started (network joining)");
    }
}

static void debug_led_stop_blink(void)
{
    if (led_blink_task_running) {
        led_blink_task_running = false;
        if (led_blink_task_handle) {
            vTaskDelay(pdMS_TO_TICKS(10));  // Give task time to exit
            led_blink_task_handle = NULL;
        }
    }
}

static void debug_led_blink_red(void)
{
    /* Blink red to indicate connection failure after max retries */
    if (!led_strip) return;
    
    for (int i = 0; i < 10; i++) {  // Blink 10 times
        led_strip_set_pixel(led_strip, 0, 16, 0, 0);  // R=16, G=0, B=0 (dim red)
        led_strip_refresh(led_strip);
        vTaskDelay(pdMS_TO_TICKS(200));  // ON for 200ms
        
        led_strip_set_pixel(led_strip, 0, 0, 0, 0);   // OFF
        led_strip_refresh(led_strip);
        vTaskDelay(pdMS_TO_TICKS(200));  // OFF for 200ms
    }
}

/* Rain gauge configuration */
#define RAIN_GAUGE_GPIO         12              // GPIO pin for rain gauge reed switch
#define RAIN_MM_PER_PULSE       0.36f           // mm of rain per bucket tip (adjust for your sensor)

/* Rain gauge variables */
typedef struct {
    uint32_t gpio_num;
    TickType_t tick;
} rain_evt_t;

static QueueHandle_t rain_gauge_evt_queue = NULL;
static float total_rainfall_mm = 0.0f;
static uint32_t rain_pulse_count = 0;
static const char *RAIN_TAG = "RAIN_GAUGE";
static bool rain_gauge_enabled = false;  // Only enable when connected to network
static bool rain_gauge_isr_installed = false;  // Track ISR installation state

/* Periodic sensor reading interval (5 minutes as per requirements) */
#define PERIODIC_READING_INTERVAL_MS (5 * 60 * 1000ULL)  // 5 minutes in milliseconds
static esp_timer_handle_t periodic_report_timer = NULL;

/* Network connection status (zigbee_network_connected declared earlier for LED functions) */
static uint32_t connection_retry_count = 0;
#define NETWORK_RETRY_SLEEP_DURATION    30      // 30 seconds for network retry
#define MAX_CONNECTION_RETRIES          20      // Max retries before giving up (10 minutes total)

/* Button action tracking (no state needed for action-based buttons) */

/********************* Define functions **************************/
static void builtin_button_callback(button_action_t action);
static void factory_reset_device(uint8_t param);
static void bme280_read_and_report(uint8_t param);
static void periodic_sensor_report_callback(void *arg);
static void start_periodic_reading(void);
static void stop_periodic_reading(void);
static void rain_gauge_init(void);
static void rain_gauge_isr_handler(void *arg);
static void rain_gauge_task(void *arg);
static void rain_gauge_zigbee_update(uint8_t param);
static void rain_gauge_enable_isr(void);
static void rain_gauge_disable_isr(void);
static esp_err_t battery_adc_init(void);
static void battery_read_and_report(uint8_t param);
static esp_err_t deferred_driver_init(void)
{
    /* Initialize builtin button with callback for factory reset */
    if (!builtin_button_driver_init(builtin_button_callback)) {
        ESP_LOGE(TAG, "Failed to initialize builtin button driver");
        return ESP_FAIL;
    }
    
    /* Initialize I2C and BME280 sensor */
    i2c_config_t i2c_cfg = {
        .mode = I2C_MODE_MASTER,
        .sda_io_num = GPIO_NUM_10,     // ESP32-H2 I2C SDA
        .scl_io_num = GPIO_NUM_11,     // ESP32-H2 I2C SCL
        .sda_pullup_en = GPIO_PULLUP_ENABLE,
        .scl_pullup_en = GPIO_PULLUP_ENABLE,
        .master.clk_speed = 100000,    // 100 KHz
    };
    
    i2c_bus_handle_t i2c_bus = i2c_bus_create(I2C_NUM_0, &i2c_cfg);
    if (i2c_bus == NULL) {
        ESP_LOGE(TAG, "Failed to create I2C bus");
        return ESP_FAIL;
    }
    
    esp_err_t ret = bme280_app_init(i2c_bus);
    if (ret != ESP_OK) {
        ESP_LOGE(TAG, "Failed to initialize BME280 sensor: %s", esp_err_to_name(ret));
        /* Don't fail completely if BME280 is not connected */
        ESP_LOGW(TAG, "Continuing without BME280 sensor");
    } else {
        ESP_LOGI(TAG, "BME280 sensor initialized successfully on ESP32-H2 (SDA:GPIO10, SCL:GPIO11)");
    }
    
    /* Initialize rain gauge */
    rain_gauge_init();
    
    /* Initialize battery ADC */
    ret = battery_adc_init();
    if (ret != ESP_OK) {
        ESP_LOGW(TAG, "Battery ADC initialization failed, will use simulated values");
    }
    
    return ESP_OK;
}

/**
 * @brief Initialize power management for light sleep
 */
static esp_err_t esp_zb_power_save_init(void)
{
    esp_err_t rc = ESP_OK;
#ifdef CONFIG_PM_ENABLE
    int cur_cpu_freq_mhz = CONFIG_ESP_DEFAULT_CPU_FREQ_MHZ;
    esp_pm_config_t pm_config = {
        .max_freq_mhz = cur_cpu_freq_mhz,
        .min_freq_mhz = cur_cpu_freq_mhz,
#if CONFIG_FREERTOS_USE_TICKLESS_IDLE
        .light_sleep_enable = true
#endif
    };
    rc = esp_pm_configure(&pm_config);
    ESP_LOGI(TAG, "Power management configured: max=%dMHz, min=%dMHz, light_sleep=%s",
             cur_cpu_freq_mhz, cur_cpu_freq_mhz, 
#if CONFIG_FREERTOS_USE_TICKLESS_IDLE
             "enabled"
#else
             "disabled"
#endif
    );
#else
    ESP_LOGW(TAG, "CONFIG_PM_ENABLE not set - light sleep may not work properly");
#endif
    return rc;
}

static void bdb_start_top_level_commissioning_cb(uint8_t mode_mask)
{
    ESP_RETURN_ON_FALSE(esp_zb_bdb_start_top_level_commissioning(mode_mask) == ESP_OK, , TAG, "Failed to start Zigbee commissioning");
}

void esp_zb_app_signal_handler(esp_zb_app_signal_t *signal_struct)
{
    uint32_t *p_sg_p       = signal_struct->p_app_signal;
    esp_err_t err_status = signal_struct->esp_err_status;
    esp_zb_app_signal_type_t sig_type = *p_sg_p;
    switch (sig_type) {
    case ESP_ZB_ZDO_SIGNAL_SKIP_STARTUP:
        ESP_LOGI(TAG, "Initialize Zigbee stack");
        debug_led_start_blink();  // Start blinking when joining network
        esp_zb_bdb_start_top_level_commissioning(ESP_ZB_BDB_MODE_INITIALIZATION);
        break;
    case ESP_ZB_ZDO_SIGNAL_LEAVE:
        ESP_LOGI(TAG, "Device is leaving the Zigbee network");
        debug_led_stop_blink();
        /* LED is already deinitialized after initial join, no action needed */
        zigbee_network_connected = false;
        rain_gauge_disable_isr();
        break;
    case ESP_ZB_BDB_SIGNAL_DEVICE_FIRST_START:
    case ESP_ZB_BDB_SIGNAL_DEVICE_REBOOT:
        /* Always initialize drivers regardless of Zigbee stack status */
        ESP_LOGI(TAG, "Deferred driver initialization %s", deferred_driver_init() ? "failed" : "successful");
        
        if (err_status == ESP_OK) {
            ESP_LOGI(TAG, "Device started up in %s factory-reset mode", esp_zb_bdb_is_factory_new() ? "" : "non");
            if (esp_zb_bdb_is_factory_new()) {
                ESP_LOGI(TAG, "Start network steering");
                debug_led_start_blink();  // Start blinking when joining network
                esp_zb_bdb_start_top_level_commissioning(ESP_ZB_BDB_MODE_NETWORK_STEERING);
            } else {
                ESP_LOGI(TAG, "Device rebooted - rejoining previous network");
                debug_led_start_blink();  // Start blinking when rejoining
                
                /* CRITICAL: Device must rejoin network after reboot!
                 * Don't mark as connected or schedule reports yet - wait for ESP_ZB_BDB_SIGNAL_STEERING success.
                 * The ESP_ZB_BDB_SIGNAL_STEERING handler will enable rain gauge and schedule initial reports. */
                esp_zb_bdb_start_top_level_commissioning(ESP_ZB_BDB_MODE_NETWORK_STEERING);
            }
        } else {
            /* commissioning failed - try to rejoin */
            ESP_LOGW(TAG, "Failed to initialize Zigbee stack (status: %s), attempting to rejoin", esp_err_to_name(err_status));
            if (!esp_zb_bdb_is_factory_new()) {
                /* Device was previously connected, try to rejoin */
                ESP_LOGI(TAG, "Attempting to rejoin previous network");
                esp_zb_bdb_start_top_level_commissioning(ESP_ZB_BDB_MODE_NETWORK_STEERING);
            }
        }
        break;
    case ESP_ZB_BDB_SIGNAL_STEERING:
        if (err_status == ESP_OK) {
            esp_zb_ieee_addr_t extended_pan_id;
            esp_zb_get_extended_pan_id(extended_pan_id);
            ESP_LOGI(TAG, "Joined network successfully (Extended PAN ID: %02x:%02x:%02x:%02x:%02x:%02x:%02x:%02x, PAN ID: 0x%04hx, Channel:%d, Short Address: 0x%04hx)",
                     extended_pan_id[7], extended_pan_id[6], extended_pan_id[5], extended_pan_id[4],
                     extended_pan_id[3], extended_pan_id[2], extended_pan_id[1], extended_pan_id[0],
                     esp_zb_get_pan_id(), esp_zb_get_current_channel(), esp_zb_get_short_address());
            
            debug_led_stop_blink();       // Stop blinking
            debug_led_set_blue();         // Set steady blue to indicate success
            
            /* Mark network as connected and reset retry count */
            zigbee_network_connected = true;
            connection_retry_count = 0;
            
            /* Enable rain gauge now that we're connected */
            rain_gauge_enable_isr();
            ESP_LOGI(RAIN_TAG, "Rain gauge enabled - device connected to Zigbee network");
            
            /* Schedule sensor data reporting after first connection 
             * Update attributes (but don't force reports) so coordinator can read current values.
             * Actual reports will be sent based on coordinator's reporting configuration.
             * After reboot, reporting config is lost and must be reconfigured by coordinator. */
            ESP_LOGI(TAG, "📊 Scheduling initial sensor data updates after network join");
            esp_zb_scheduler_alarm((esp_zb_callback_t)bme280_read_and_report, 0, 2000); // Update in 2 seconds
            esp_zb_scheduler_alarm((esp_zb_callback_t)rain_gauge_zigbee_update, 0, 3000); // Update in 3 seconds  
            esp_zb_scheduler_alarm((esp_zb_callback_t)battery_read_and_report, 0, 4000); // Update in 4 seconds
            
            /* Start periodic sensor reading timer for 15-minute intervals.
             * This ensures sensors are read regularly and attributes stay updated.
             * Actual reporting to coordinator is controlled by Zigbee reporting configuration. */
            start_periodic_reading();
            
            /* Deinitialize LED after successful join - LED kept on briefly to confirm join */
            ESP_LOGI(TAG, "💡 LED will power down in 5 seconds to save battery");
            esp_zb_scheduler_alarm((esp_zb_callback_t)debug_led_deinit, 0, 5000); // Power down LED
            
            /* Device will enter light sleep automatically when all initial reports complete */
            ESP_LOGI(TAG, "💤 Initial reports scheduled - device will sleep when idle");
        } else {
            ESP_LOGI(TAG, "Network steering was not successful (status: %s)", esp_err_to_name(err_status));
            
            /* Mark network as disconnected and increment retry count */
            zigbee_network_connected = false;
            connection_retry_count++;
            
            /* Disable rain gauge when not connected */
            rain_gauge_disable_isr();
            ESP_LOGW(RAIN_TAG, "Rain gauge disabled - not connected to network");
            
            /* Stop periodic sensor reading timer when disconnected */
            stop_periodic_reading();
            
            /* Check if max retries reached */
            if (connection_retry_count >= MAX_CONNECTION_RETRIES) {
                ESP_LOGE(TAG, "❌ Max connection retries (%d) reached - giving up", MAX_CONNECTION_RETRIES);
                debug_led_stop_blink();
                debug_led_blink_red();  // Blink red to indicate failure
                /* LED will be deinitialized after red blink sequence completes */
                esp_zb_scheduler_alarm((esp_zb_callback_t)debug_led_deinit, 0, 5000);
                /* Device will continue to operate but won't retry network join */
                break;
            }
            
            ESP_LOGW(TAG, "🔄 Connection attempt %d/%d failed - retrying", connection_retry_count, MAX_CONNECTION_RETRIES);
            esp_zb_scheduler_alarm((esp_zb_callback_t)bdb_start_top_level_commissioning_cb, ESP_ZB_BDB_MODE_NETWORK_STEERING, 1000);
        }
        break;
    case ESP_ZB_COMMON_SIGNAL_CAN_SLEEP:
        /* Check if OTA upgrade is in progress - MUST NOT sleep during OTA! */
        if (esp_zb_ota_is_active()) {
            ESP_LOGW(TAG, "⚠️ OTA upgrade in progress - preventing sleep");
            /* Don't call esp_zb_sleep_now() - let OTA complete */
            break;
        }        
        
        /* LED is already deinitialized after successful join - no action needed */
        esp_zb_sleep_now();
        break;
    default:
        ESP_LOGI(TAG, "ZDO signal: %s (0x%x), status: %s", esp_zb_zdo_signal_to_string(sig_type), sig_type,
                 esp_err_to_name(err_status));
        break;
    }
}

static esp_err_t zb_attribute_handler(const esp_zb_zcl_set_attr_value_message_t *message)
{
    esp_err_t ret = ESP_OK;

    ESP_RETURN_ON_FALSE(message, ESP_FAIL, TAG, "Empty message");
    ESP_RETURN_ON_FALSE(message->info.status == ESP_ZB_ZCL_STATUS_SUCCESS, ESP_ERR_INVALID_ARG, TAG, "Received message: error status(%d)",
                        message->info.status);
    ESP_LOGI(TAG, "Received message: endpoint(%d), cluster(0x%x), attribute(0x%x), data size(%d)", message->info.dst_endpoint, message->info.cluster,
             message->attribute.id, message->attribute.data.size);
    
    /* No custom attribute handling needed - all attributes managed by standard Zigbee reporting */
    
    return ret;
}
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
void app_main(void)
{
    /* Initialize NVS */
    ESP_ERROR_CHECK(nvs_flash_init());
    
    /* Initialize debug LED */
    debug_led_init();
    
    /* Initialize OTA */
    ESP_ERROR_CHECK(esp_zb_ota_init());
    
    /* Initialize power management for light sleep */
    ESP_ERROR_CHECK(esp_zb_power_save_init());
    
    /* Enable GPIO wakeup globally for light sleep */
    esp_err_t gpio_wake_ret = esp_sleep_enable_gpio_wakeup();
    if (gpio_wake_ret == ESP_OK) {
        ESP_LOGI(TAG, "✅ GPIO wakeup enabled for light sleep");
    } else {
        ESP_LOGW(TAG, "⚠️ Failed to enable GPIO wakeup: %s", esp_err_to_name(gpio_wake_ret));
    }
    
    /* Check wake-up reason and print statistics */
    wake_reason_t wake_reason = check_wake_reason();
    print_wake_statistics();
    
    /* Load rainfall data from RTC/NVS */
    float rainfall_mm = 0.0f;
    uint32_t pulse_count = 0;
    load_rainfall_data(&rainfall_mm, &pulse_count);
    
    /* Print battery life estimate (assuming 2500mAh battery) */
    estimate_battery_life(2500);
    
    /* Configure ESP-IDF platform */
    esp_zb_platform_config_t config = {
        .radio_config = ESP_ZB_DEFAULT_RADIO_CONFIG(),
        .host_config = ESP_ZB_DEFAULT_HOST_CONFIG(),
    };
    ESP_ERROR_CHECK(esp_zb_platform_config(&config));
    
    /* Start Zigbee task */
    ESP_LOGI(TAG, "🚀 Starting Caelum Weather Station (Battery Mode)");
    
    /* Log firmware version from app description */
    esp_app_desc_t app_desc_main;
    const esp_partition_t *running = esp_ota_get_running_partition();
    if (esp_ota_get_partition_description(running, &app_desc_main) == ESP_OK) {
        ESP_LOGI(TAG, "📦 Firmware: %s (Date: %s %s)", app_desc_main.version, app_desc_main.date, app_desc_main.time);
    }
    
    #ifdef OTA_FILE_VERSION
        ESP_LOGI(TAG, "⚙️  OTA: Version=0x%08lX, Manufacturer=0x%04X, ImageType=0x%04X", 
                (unsigned long)OTA_FILE_VERSION, OTA_UPGRADE_MANUFACTURER, OTA_UPGRADE_IMAGE_TYPE);
    #else
        ESP_LOGI(TAG, "⚙️  OTA: Manufacturer=0x%04X, ImageType=0x%04X", OTA_UPGRADE_MANUFACTURER, OTA_UPGRADE_IMAGE_TYPE);
    #endif

    ESP_LOGI(TAG, "Wake reason: %s", 
             wake_reason == WAKE_REASON_TIMER ? "TIMER" :
             wake_reason == WAKE_REASON_RAIN ? "RAIN" :
             wake_reason == WAKE_REASON_BUTTON ? "BUTTON" : "RESET");
    
    /* Log network connection status */
    if (zigbee_network_connected) {
        ESP_LOGI(TAG, "📡 Network: Connected");
    } else {
        ESP_LOGW(TAG, "📡 Network: Disconnected (retries: %d/%d)", connection_retry_count, MAX_CONNECTION_RETRIES);
    }
    
    xTaskCreate(esp_zb_task, "Zigbee_main", 4096, NULL, 5, NULL);
}

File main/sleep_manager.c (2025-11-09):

/*
 * SPDX-FileCopyrightText: 2025 Espressif Systems (Shanghai) CO LTD
 *
 * SPDX-License-Identifier:  LicenseRef-Included
 *
 * ESP32-H2 Light Sleep Management for Weather Station
 *
 * This file implements light sleep functionality for battery-powered operation
 * with maintained Zigbee network connection for instant wake and reporting
 */

#include "esp_sleep.h"
#include "esp_log.h"
#include "esp_timer.h"
#include "driver/gpio.h"
#include "driver/rtc_io.h"
#include "nvs_flash.h"
#include "nvs.h"
#include "esp_zigbee_core.h"
#include "esp_zb_weather.h"
#include "freertos/FreeRTOS.h"
#include "freertos/task.h"

static const char *SLEEP_TAG = "SLEEP";

/* RTC memory to persist data across sleep cycles */
static RTC_DATA_ATTR uint32_t boot_count = 0;
static RTC_DATA_ATTR float rtc_rainfall_mm = 0.0f;
static RTC_DATA_ATTR uint32_t rtc_rain_pulse_count = 0;
static RTC_DATA_ATTR int64_t last_report_timestamp = 0;

/* Wake-up reason tracking */
typedef enum {
    WAKE_REASON_TIMER = 0,
    WAKE_REASON_RAIN,
    WAKE_REASON_BUTTON,
    WAKE_REASON_RESET
} wake_reason_t;

/**
 * @brief Get and log the wake-up reason
 * @return wake_reason_t The reason for wake-up
 */
wake_reason_t check_wake_reason(void)
{
    esp_sleep_wakeup_cause_t wakeup_reason = esp_sleep_get_wakeup_cause();
    
    boot_count++;
    ESP_LOGI(SLEEP_TAG, "🔄 Wake-up #%lu", boot_count);
    
    switch (wakeup_reason) {
        case ESP_SLEEP_WAKEUP_TIMER:
            ESP_LOGI(SLEEP_TAG, "⏰ Wake-up reason: TIMER (periodic 15-minute interval)");
            return WAKE_REASON_TIMER;
            
        case ESP_SLEEP_WAKEUP_EXT0:
        case ESP_SLEEP_WAKEUP_EXT1:
            ESP_LOGI(SLEEP_TAG, "🌧️ Wake-up reason: RAIN DETECTED on GPIO%d", RAIN_WAKE_GPIO);
            return WAKE_REASON_RAIN;
            
        case ESP_SLEEP_WAKEUP_GPIO:
            ESP_LOGI(SLEEP_TAG, "🔘 Wake-up reason: BUTTON press");
            return WAKE_REASON_BUTTON;
            
        case ESP_SLEEP_WAKEUP_UNDEFINED:
        default:
            ESP_LOGI(SLEEP_TAG, "🔌 Wake-up reason: POWER ON / RESET");
            // Reset RTC memory on first boot
            if (boot_count == 1) {
                rtc_rainfall_mm = 0.0f;
                rtc_rain_pulse_count = 0;
                last_report_timestamp = 0;
            }
            return WAKE_REASON_RESET;
    }
}

/**
 * @brief Configure GPIO for wake-up from deep sleep
 * @param gpio_num GPIO number to use for wake-up
 * @param level Wake-up level (0=low, 1=high)
 */
void configure_gpio_wakeup(gpio_num_t gpio_num, int level)
{
    ESP_LOGI(SLEEP_TAG, "Configuring GPIO%d for wake-up on %s", gpio_num, level ? "HIGH" : "LOW");
    
    /* Check if GPIO is RTC capable first */
    if (!rtc_gpio_is_valid_gpio(gpio_num)) {
        ESP_LOGW(SLEEP_TAG, "⚠️  GPIO%d is not RTC capable - rain detection during sleep disabled", gpio_num);
        ESP_LOGI(SLEEP_TAG, "ℹ️  Rain will only be detected when device is awake (timer-based wake-ups every 15min)");
        return;
    }
    
    /* Configure the GPIO as input with pull-down (for active-high rain gauge) */
    gpio_config_t io_conf = {
        .pin_bit_mask = (1ULL << gpio_num),
        .mode = GPIO_MODE_INPUT,
        .pull_up_en = GPIO_PULLUP_DISABLE,
        .pull_down_en = GPIO_PULLDOWN_ENABLE,  // Pull down so HIGH pulse wakes us up
        .intr_type = GPIO_INTR_DISABLE
    };
    gpio_config(&io_conf);
    
    /* Enable wake-up on this GPIO going HIGH */
    esp_err_t ret = esp_sleep_enable_ext1_wakeup((1ULL << gpio_num), ESP_EXT1_WAKEUP_ANY_HIGH);
    if (ret == ESP_OK) {
        ESP_LOGI(SLEEP_TAG, "✅ GPIO%d wake-up configured (trigger on HIGH)", gpio_num);
    } else {
        ESP_LOGE(SLEEP_TAG, "❌ Failed to configure GPIO%d wake-up: %s", gpio_num, esp_err_to_name(ret));
        ESP_LOGI(SLEEP_TAG, "ℹ️  Rain will only be detected during timer wake-ups");
    }
}

/**
 * @brief Save rainfall data to RTC memory and NVS
 * @param rainfall_mm Current total rainfall in mm
 * @param pulse_count Current pulse count
 */
void save_rainfall_data(float rainfall_mm, uint32_t pulse_count)
{
    // Save to RTC memory (fast, survives sleep)
    rtc_rainfall_mm = rainfall_mm;
    rtc_rain_pulse_count = pulse_count;
    
    ESP_LOGI(SLEEP_TAG, "💾 Saved to RTC: %.2f mm, %lu pulses", rtc_rainfall_mm, rtc_rain_pulse_count);
    
    // Also save to NVS for persistence across power loss
    nvs_handle_t nvs_handle;
    esp_err_t ret = nvs_open("rain_storage", NVS_READWRITE, &nvs_handle);
    if (ret == ESP_OK) {
        nvs_set_blob(nvs_handle, "rainfall", &rainfall_mm, sizeof(float));
        nvs_set_u32(nvs_handle, "pulses", pulse_count);
        nvs_commit(nvs_handle);
        nvs_close(nvs_handle);
        ESP_LOGI(SLEEP_TAG, "💾 Saved to NVS: %.2f mm, %lu pulses", rainfall_mm, pulse_count);
    }
}

/**
 * @brief Load rainfall data from RTC memory or NVS
 * @param rainfall_mm Pointer to store rainfall value
 * @param pulse_count Pointer to store pulse count
 * @return true if data loaded from RTC, false if loaded from NVS
 */
bool load_rainfall_data(float *rainfall_mm, uint32_t *pulse_count)
{
    // Check if we have valid RTC data (from previous sleep cycle)
    if (boot_count > 1 && rtc_rainfall_mm >= 0.0f) {
        *rainfall_mm = rtc_rainfall_mm;
        *pulse_count = rtc_rain_pulse_count;
        ESP_LOGI(SLEEP_TAG, "📂 Loaded from RTC: %.2f mm, %lu pulses", *rainfall_mm, *pulse_count);
        return true;
    }
    
    // Otherwise, try to load from NVS
    nvs_handle_t nvs_handle;
    esp_err_t ret = nvs_open("rain_storage", NVS_READONLY, &nvs_handle);
    if (ret == ESP_OK) {
        size_t size = sizeof(float);
        ret = nvs_get_blob(nvs_handle, "rainfall", rainfall_mm, &size);
        if (ret == ESP_OK) {
            nvs_get_u32(nvs_handle, "pulses", pulse_count);
            nvs_close(nvs_handle);
            ESP_LOGI(SLEEP_TAG, "📂 Loaded from NVS: %.2f mm, %lu pulses", *rainfall_mm, *pulse_count);
            
            // Update RTC memory
            rtc_rainfall_mm = *rainfall_mm;
            rtc_rain_pulse_count = *pulse_count;
            return false;
        }
        nvs_close(nvs_handle);
    }
    
    // No stored data, start fresh
    *rainfall_mm = 0.0f;
    *pulse_count = 0;
    ESP_LOGI(SLEEP_TAG, "📂 No stored data, starting from 0.0 mm");
    return false;
}
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

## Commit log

2025-11-05 Update README and esp_zb_weather.c to enhance rain gauge functionality and sleep management
    - Revised project description and added details for the new 3-endpoint design in README.md.
    - Implemented deferred driver initialization and improved logging in esp_zb_weather.c.
    - Removed unused NVS functions for rain gauge data storage, now handled by sleep manager.
    - Enhanced rain gauge task with better ISR handling and periodic debug logging.
    - Scheduled final sensor reporting before deep sleep and ensured Zigbee stack suspension.
2025-11-06 Add battery monitoring functionality and update ADC configuration
2025-11-06 Refactor converter for battery monitoring: remove manual handling of battery data and streamline integration with existing functionality
2025-11-06 Add debug LED functionality for network status indication
2025-11-08 Update build number to 20 and adjust sensor reporting delays for improved performance
2025-11-09 Migrate from deep sleep to light sleep mode for ESP32-H2 Weather Station, enhancing responsiveness and maintaining Zigbee connection. Update related functions and documentation.
2025-11-12 Refactor initial sensor data reporting and LED deinitialization logic for improved battery efficiency. Update reporting configuration to ensure persistence across reboots and enhance logging for attr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
    [esp_zb_weather.c]
2025-11-12 Remove optional sleep cycle logging to reduce power consumption during sleep. Ensure LED deinitialization is handled after successful join.
2025-11-15 Update partitions.csv for ESP32-H2 with 4MB Flash configuration
    - Adjusted partition sizes and offsets to optimize for OTA updates.
    - Reduced NVS size to 0x4000 and updated offsets for phy_init and otadata.
    - Modified OTA partition sizes to fit within the new 4MB flash limit.
    - Ensured compatibility with the new memory layout for better performance.
    [caelum.kicad_pcb, caelum.kicad_sch, partitions.csv]
2025-12-14 Add PCB v2
    [caelum_v2-B_Cu.gbl, caelum_v2-B_Mask.gbs, caelum_v2-B_Paste.gbp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]
2025-12-15 Update PCB V2
    [caelum.kicad_pcb, caelum_v2.kicad_pcb, caelum_v2.kicad_sch]

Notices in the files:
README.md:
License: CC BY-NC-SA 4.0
